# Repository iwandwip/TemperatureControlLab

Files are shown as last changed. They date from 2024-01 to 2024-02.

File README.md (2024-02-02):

# Temperature Control Lab - AP Monitor
The temperature control lab is an application of feedback control with an Arduino, an LED, two heaters, and two temperature sensors. The heater power output is adjusted to maintain a desired temperature setpoint. Thermal energy from the heater is transferred by conduction, convection, and radiation to the temperature sensor. Heat is also transferred away from the device to the surroundings.

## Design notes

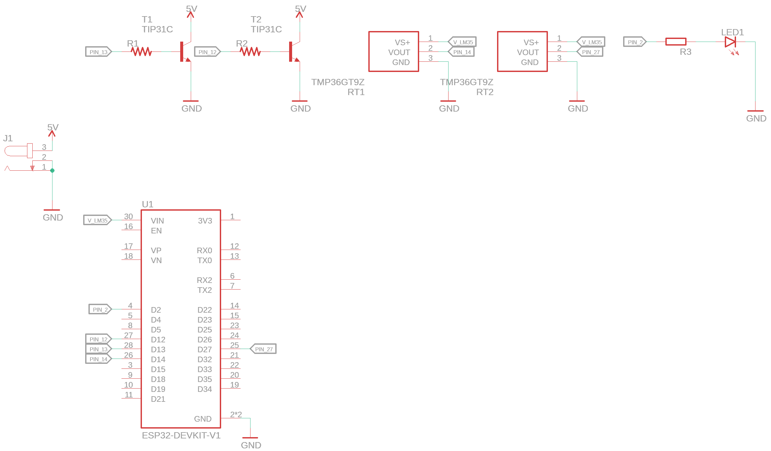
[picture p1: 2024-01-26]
pcb/esp32/sch.png

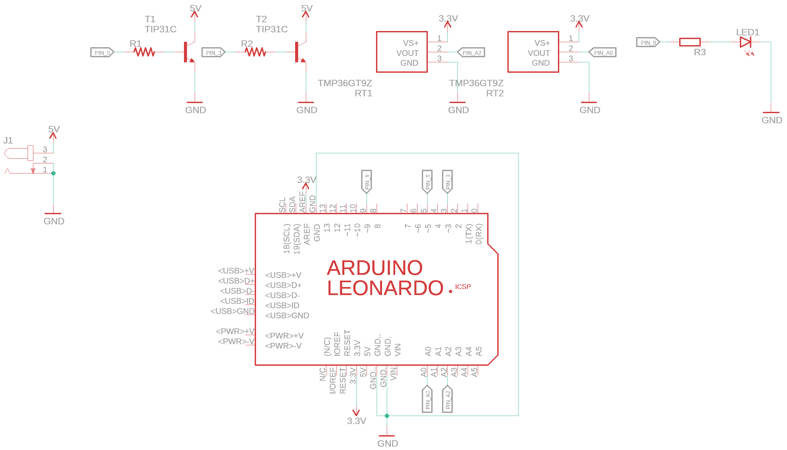
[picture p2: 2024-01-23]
pcb/leonardo/sch.png

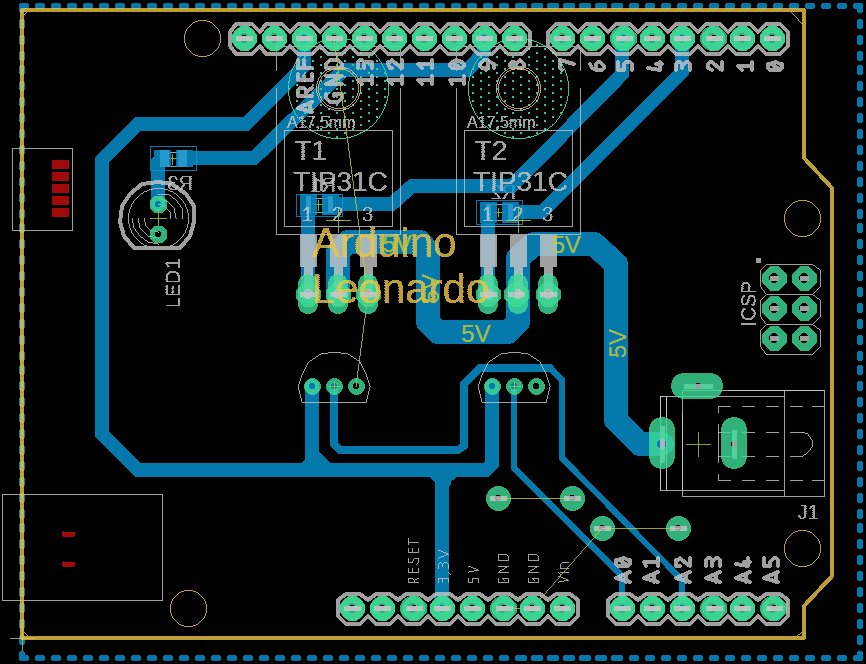
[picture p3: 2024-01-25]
pcb/leonardo/brd.png

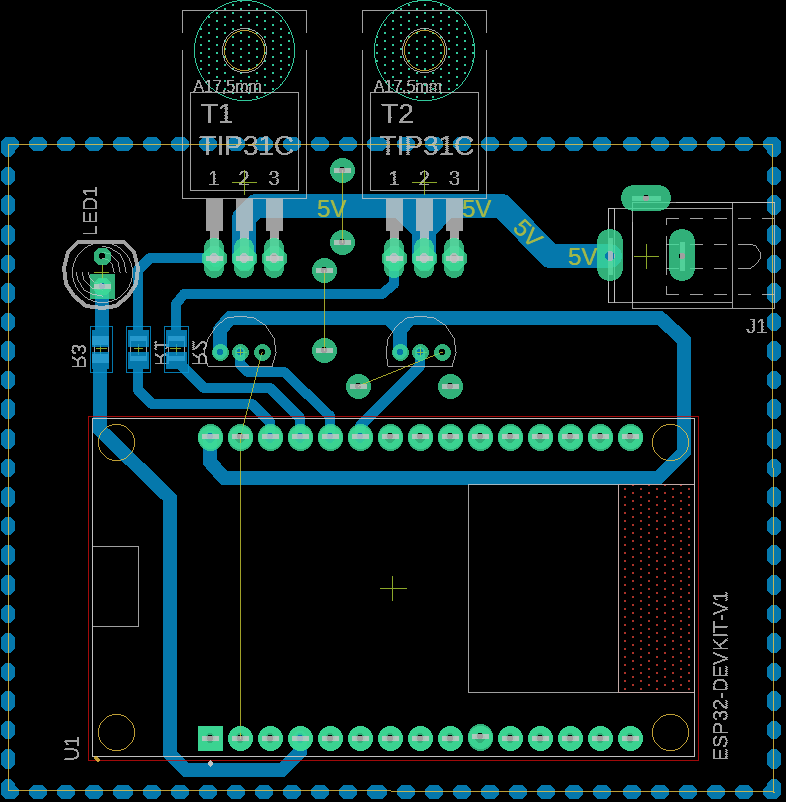
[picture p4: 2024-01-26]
pcb/esp32/brd.png

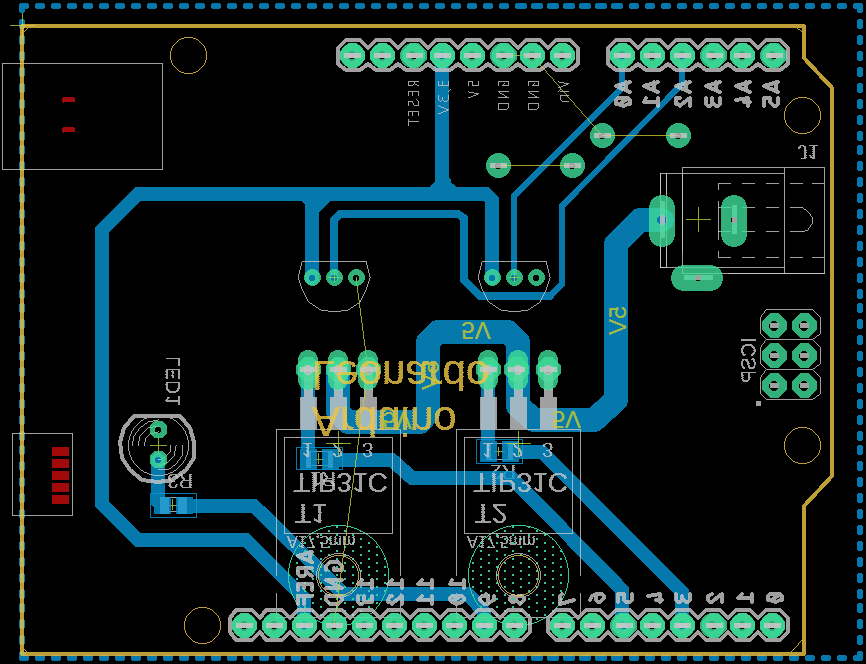
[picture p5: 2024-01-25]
pcb/leonardo/brd-mirror.png

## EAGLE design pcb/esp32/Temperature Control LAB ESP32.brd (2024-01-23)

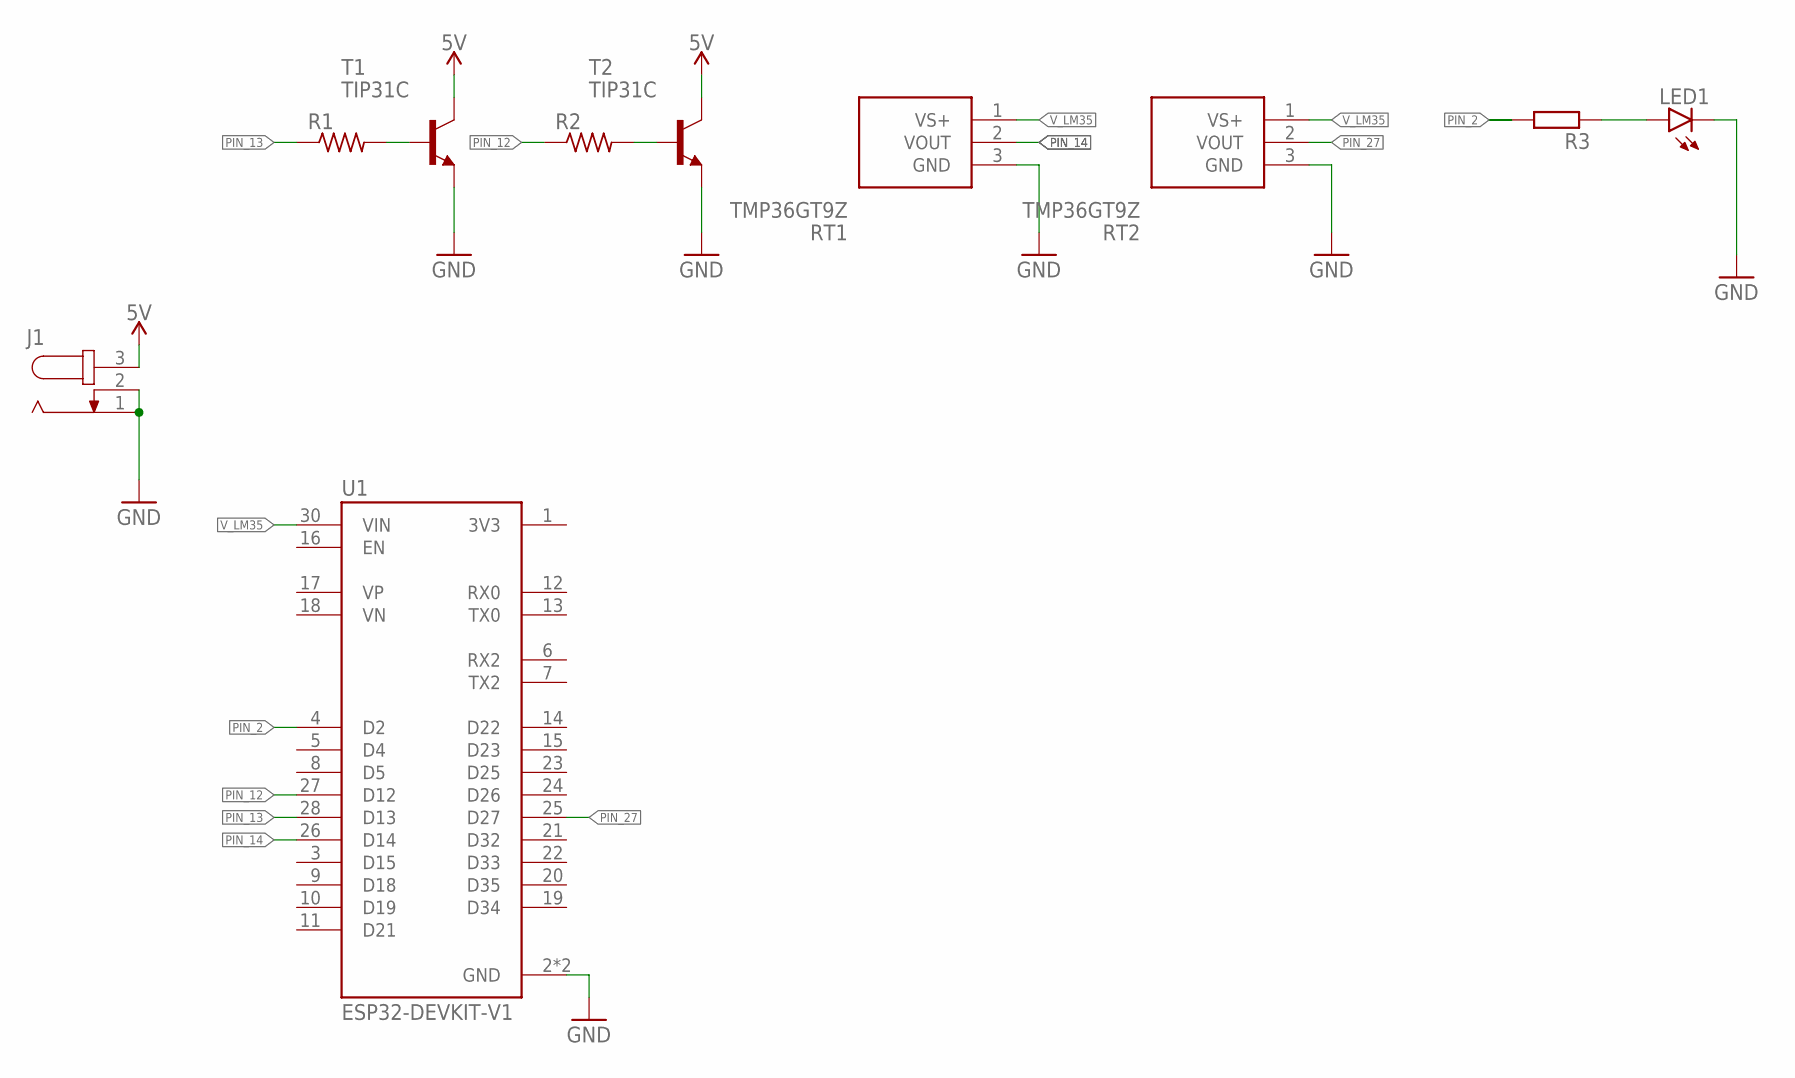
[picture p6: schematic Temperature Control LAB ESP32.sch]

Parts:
J1: JACK-PLUG0; SPC4077
LED1: LED5MM
R1, R2: R-US_M0805; M0805
R3: R-EU_R0805; R0805
RT1, RT2: TMP36GT9Z; TO-92
T1, T2: TIP31C; TO220
U1: ESP32-DEVKIT-V1; MODULE_ESP32_DEVKIT_V1

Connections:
5V: J1.3, T1.2 (C), T2.2 (C)
GND: J1.1, J1.2, LED1.K (C), RT1.3 (GND), RT2.3 (GND), T1.3 (E), T2.3 (E), U1.2 (GND), U1.29 (GND)
unnamed: R1.2, T1.1 (B)
unnamed: R2.2, T2.1 (B)
unnamed: LED1.A, R3.1
PIN_2: R3.2, U1.4 (D2)
PIN_12: R2.1, U1.27 (D12)
PIN_13: R1.1, U1.28 (D13)
PIN_14: RT1.2 (VOUT), U1.26 (D14)
PIN_27: RT2.2 (VOUT), U1.25 (D27)
V_LM35: RT1.1 (VS+), RT2.1 (VS+), U1.30 (VIN)

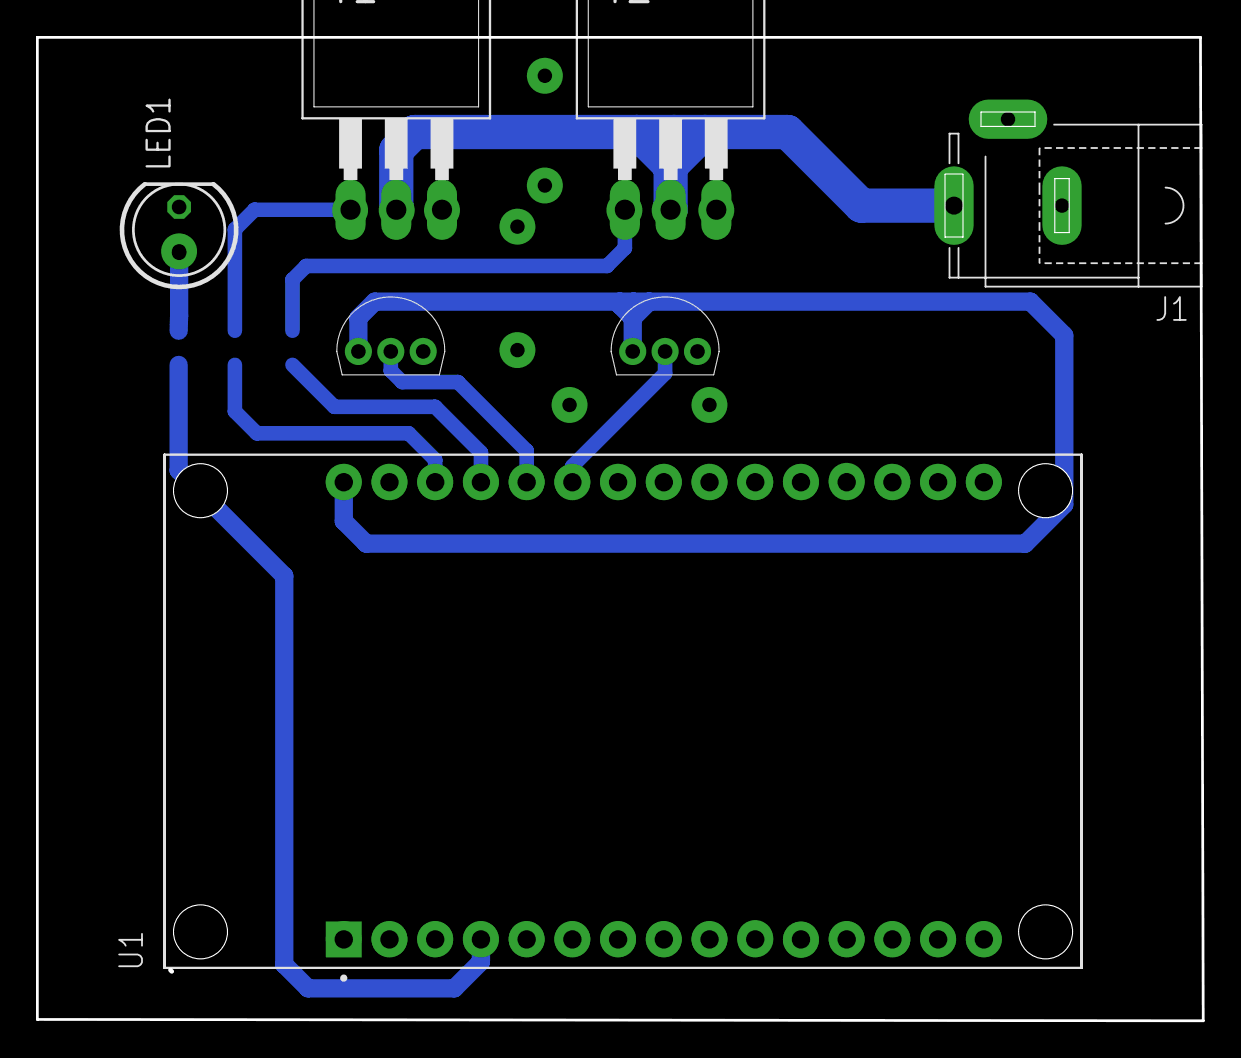
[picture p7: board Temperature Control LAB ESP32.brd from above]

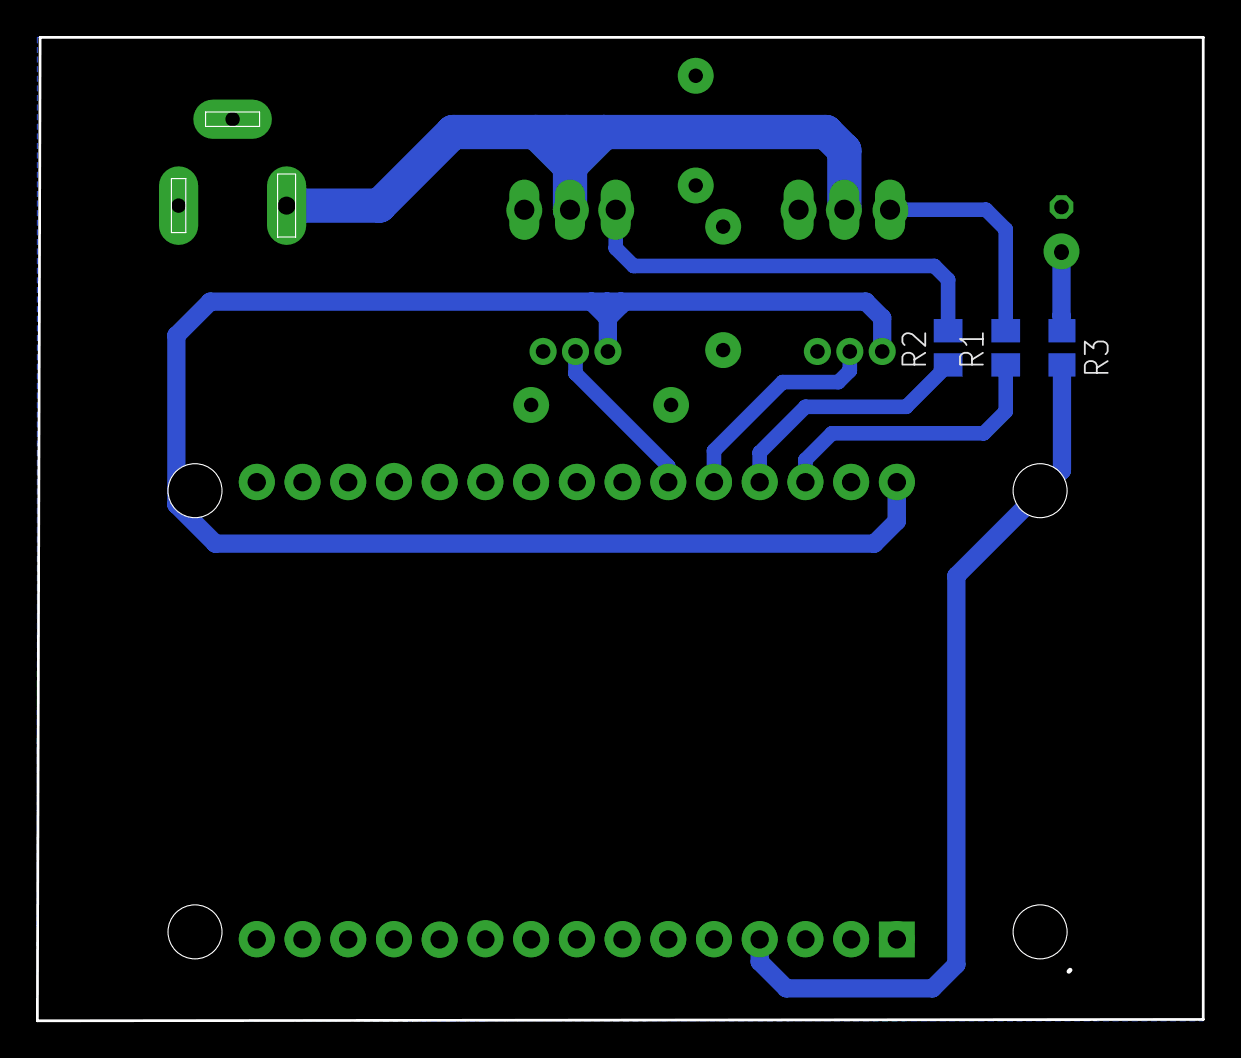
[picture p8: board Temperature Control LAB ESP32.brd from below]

Board: 2 copper layers, 64.8 x 54.6 mm, 10 parts (3 on the bottom side), 11 nets.

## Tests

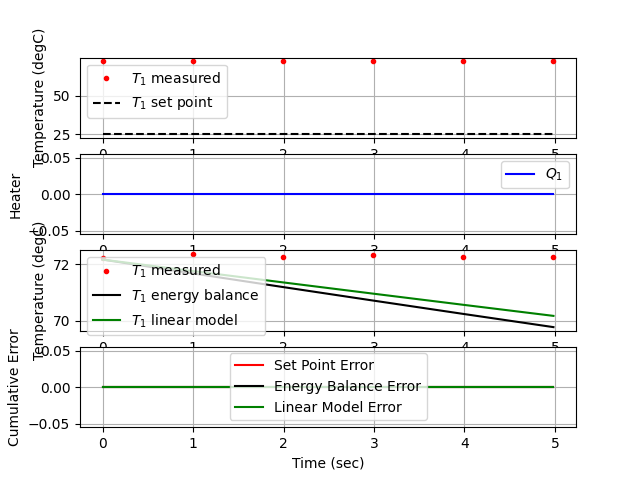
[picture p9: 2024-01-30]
sketch/py/test_PID.png

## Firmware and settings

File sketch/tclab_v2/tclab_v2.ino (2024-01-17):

/* https://apmonitor.com/pdc/index.php/Main/ArduinoTemperatureControl
  TCLab Temperature Control Lab Firmware
  Jeffrey Kantor, Bill Tubbs, John Hedengren, Shawn Summey
  February 2021

  This firmware provides a high level interface to the Temperature Control Lab. The
  firmware scans the serial port for commands. Commands are case-insensitive. Any
  unrecognized command results in sleep model. Each command returns a result string.

  A         software restart. Returns "Start".
  LED float set LED to float for 10 sec. range 0 to 100. Returns actual float
  P1 float  set pwm limit on heater 1, range 0 to 255. Default 200. Returns P1.
  P2 float  set pwm limit on heater 2, range 0 to 255. Default 100. Returns P2.
  Q1 float  set Heater 1, range 0 to 100. Returns value of Q1.
  Q2 float  set Heater 2, range 0 to 100. Returns value of Q2.
  Q1B float set Heater 1, range 0 to 100. Returns value of Q1 as a 32-bit float.
  Q2B float set Heater 2, range 0 to 100. Returns value of Q2 as a 32-bit float.
  R1        get value of Heater 1, range 0 to 100
  R2        get value of Heater 2, range 0 to 100
  SCAN      get values T1 T2 Q1 Q1 in line delimited values
  T1        get Temperature T1. Returns value of T1 in °C.
  T2        get Temperature T2. Returns value of T2 in °C.
  T1B       get Temperature T1. Returns value of T1 in °C as a 32-bit float.
  T2B       get Temperature T2. Returns value of T2 in °C as a 32-bit float.
  VER       get firmware version string
  X         stop, enter sleep mode. Returns "Stop"

  Limits on the heater power can be configured with the constants below.

  Status is indicated by LED1 on the Temperature Control Lab. Status conditions are:

      LED1        LED1
      Brightness  State
      ----------  -----
      dim         steady     Normal operation, heaters off
      bright      steady     Normal operation, heaters on
      dim         blinking   High temperature alarm on, heaters off
      bright      blinking   High temperature alarm on, heaters on

  The Temperature Control Lab shuts down the heaters if it receives no host commands
  during a timeout period (configure below), receives an "X" command, or receives
  an unrecognized command from the host.

  Constants are used to configure the firmware.

  Changelog ordered by Semantic Version
  
      1.0.1 first version included in the tclab package
      1.1.0 added R1 and R2 commands to read current heater values
            changed heater values to units of percent of full power
            added P1 and P2 commands to set heater power limits
            changed readCommand to avoid busy states
            changed simplified LED status model
      1.2.0 added LED command
      1.2.1 fixed reset heater values on close
            added version history
      1.2.2 changed version string for better display by TCLab
      1.2.3 changed baudrate to from 9600 to 115200
      1.3.0 added SCAN function 
            added board type in version string
      1.4.0 changed Q1 and Q2 to float from int
      1.4.1 fixed missing Serial.flush() at end of command loop
      1.4.2 fixed bug with X command
      1.4.3 deprecated use of Arduino IDE Version < 1.0.0
      1.5.0 removed webusb
      1.6.0 changed temperature to average 10 measurements to reduce noise
      2.0.0 added binary communications.
            added T1B and T2B commands return 32-bit float
            added Q1B and Q2B commands return 32-bit float confirmation of heater setting
            added calculation to use 1.75 AREF to match TMP36 voltage range 
      2.0.1 added updates to Notre Dame and BYU versions of this firmware
            changed version history to standard change log practices

*/

#include "Arduino.h"

// determine board type
#if defined(__AVR_ATmega328P__) || defined(__AVR_ATmega168__)
String boardType = "Arduino Uno";
#elif defined(__AVR_ATmega32U4__) || defined(__AVR_ATmega16U4__)
String boardType = "Arduino Leonardo/Micro";
#elif defined(__AVR_ATmega1280__) || defined(__AVR_ATmega2560__)
String boardType = "Arduino Mega";
#else
String boardType = "Unknown board";
#endif

// Enable debugging output
const bool DEBUG = false;

// constants
const String vers = "2.0.1";  // version of this firmware
const long baud = 115200;     // serial baud rate
const char sp = ' ';          // command separator
const char nl = '\n';         // command terminator

// pin numbers corresponding to signals on the TC Lab Shield
const int pinT1 = A0;   // T1
const int pinT2 = A2;   // T2
const int pinQ1 = 3;    // Q1
const int pinQ2 = 5;    // Q2
const int pinLED1 = 9;  // LED1

// temperature alarm limits
const int limT1 = 50;  // T1 high alarm (°C)
const int limT2 = 50;  // T2 high alarm (°C)

// LED1 levels
const int hiLED = 60;          // hi LED
const int loLED = hiLED / 16;  // lo LED

// global variables
char Buffer[64];          // buffer for parsing serial input
int buffer_index = 0;     // index for Buffer
String cmd;               // command
float val;                // command value
int ledStatus;            // 1: loLED
                          // 2: hiLED
                          // 3: loLED blink
                          // 4: hiLED blink
long ledTimeout = 0;      // when to return LED to normal operation
float LED = 100;          // LED override brightness
float P1 = 200;           // heater 1 power limit in units of pwm. Range 0 to 255
float P2 = 100;           // heater 2 power limit in units in pwm, range 0 to 255
float Q1 = 0;             // last value written to heater 1 in units of percent
float Q2 = 0;             // last value written to heater 2 in units of percent
int alarmStatus;          // hi temperature alarm status
boolean newData = false;  // boolean flag indicating new command
int n = 10;               // number of samples for each temperature measurement


void readCommand() {
  while (Serial && (Serial.available() > 0) && (newData == false)) {
    int byte = Serial.read();
    if ((byte != '\r') && (byte != nl) && (buffer_index < 64)) {
      Buffer[buffer_index] = byte;
      buffer_index++;
    } else {
      newData = true;
    }
  }
}

// for debugging with the serial monitor in Arduino IDE
void echoCommand() {
  if (newData) {
    Serial.write("Received Command: ");
    Serial.write(Buffer, buffer_index);
    Serial.write(nl);
    Serial.flush();
  }
}

// return average  of n reads of thermister temperature in °C
inline float readTemperature(int pin) {
  float degC = 0.0;
  for (int i = 0; i < n; i++) {
    degC += analogRead(pin) * 0.322265625 - 50.0;  // use for 3.3v AREF
    //degC += analogRead(pin) * 0.170898438 - 50.0;  // use for 1.75v AREF
  }
  return degC / float(n);
}

void parseCommand(void) {
  if (newData) {
    String read_ = String(Buffer);

    // separate command from associated data
    int idx = read_.indexOf(sp);
    cmd = read_.substring(0, idx);
    cmd.trim();
    cmd.toUpperCase();

    // extract data. toFloat() returns 0 on error
    String data = read_.substring(idx + 1);
    data.trim();
    val = data.toFloat();

    // reset parameter for next command
    memset(Buffer, 0, sizeof(Buffer));
    buffer_index = 0;
    newData = false;
  }
}

void sendResponse(String msg) {
  Serial.println(msg);
}

void sendFloatResponse(float val) {
  Serial.println(String(val, 3));
}

void sendBinaryResponse(float val) {
  byte *b = (byte *)&val;
  Serial.write(b, 4);
}

void dispatchCommand(void) {
  if (cmd == "A") {
    setHeater1(0);
    setHeater2(0);
    sendResponse("Start");
  } else if (cmd == "LED") {
    ledTimeout = millis() + 10000;
    LED = max(0, min(100, val));
    sendResponse(String(LED));
  } else if (cmd == "P1") {
    P1 = max(0, min(255, val));
    sendResponse(String(P1));
  } else if (cmd == "P2") {
    P2 = max(0, min(255, val));
    sendResponse(String(P2));
  } else if (cmd == "Q1") {
    setHeater1(val);
    sendFloatResponse(Q1);
  } else if (cmd == "Q1B") {
    setHeater1(val);
    sendBinaryResponse(Q1);
  } else if (cmd == "Q2") {
    setHeater2(val);
    sendFloatResponse(Q2);
  } else if (cmd == "Q2B") {
    setHeater1(val);
    sendBinaryResponse(Q2);
  } else if (cmd == "R1") {
    sendFloatResponse(Q1);
  } else if (cmd == "R2") {
    sendFloatResponse(Q2);
  } else if (cmd == "SCAN") {
    sendFloatResponse(readTemperature(pinT1));
    sendFloatResponse(readTemperature(pinT2));
    sendFloatResponse(Q1);
    sendFloatResponse(Q2);
  } else if (cmd == "T1") {
    sendFloatResponse(readTemperature(pinT1));
  } else if (cmd == "T1B") {
    sendBinaryResponse(readTemperature(pinT1));
  } else if (cmd == "T2") {
    sendFloatResponse(readTemperature(pinT2));
  } else if (cmd == "T2B") {
    sendBinaryResponse(readTemperature(pinT2));
  } else if (cmd == "VER") {
    sendResponse("TCLab Firmware " + vers + " " + boardType);
  } else if (cmd == "X") {
    setHeater1(0);
    setHeater2(0);
    sendResponse("Stop");
  } else if (cmd.length() > 0) {
    setHeater1(0);
    setHeater2(0);
    sendResponse(cmd);
  }
  Serial.flush();
  cmd = "";
}

void checkAlarm(void) {
  if ((readTemperature(pinT1) > limT1) or (readTemperature(pinT2) > limT2)) {
    alarmStatus = 1;
  } else {
    alarmStatus = 0;
  }
}

void updateStatus(void) {
  // determine led status
  ledStatus = 1;
  if ((Q1 > 0) or (Q2 > 0)) {
    ledStatus = 2;
  }
  if (alarmStatus > 0) {
    ledStatus += 2;
  }
  // update led depending on ledStatus
  if (millis() < ledTimeout) {  // override led operation
    analogWrite(pinLED1, LED);
  } else {
    switch (ledStatus) {
      case 1:  // normal operation, heaters off
        analogWrite(pinLED1, loLED);
        break;
      case 2:  // normal operation, heater on
        analogWrite(pinLED1, hiLED);
        break;
      case 3:  // high temperature alarm, heater off
        if ((millis() % 2000) > 1000) {
          analogWrite(pinLED1, loLED);
        } else {
          analogWrite(pinLED1, loLED / 4);
        }
        break;
      case 4:  // high temperature alarm, heater on
        if ((millis() % 2000) > 1000) {
          analogWrite(pinLED1, hiLED);
        } else {
          analogWrite(pinLED1, loLED);
        }
        break;
    }
  }
}

// set Heater 1
void setHeater1(float qval) {
  Q1 = max(0., min(qval, 100.));
  analogWrite(pinQ1, (Q1 * P1) / 100);
}

// set Heater 2
void setHeater2(float qval) {
  Q2 = max(0., min(qval, 100.));
  analogWrite(pinQ2, (Q2 * P2) / 100);
}

// arduino startup
void setup() {
  analogReference(EXTERNAL);
  while (!Serial) {
    ;  // wait for serial port to connect.
  }
  Serial.begin(baud);
  Serial.flush();
  setHeater1(0);
  setHeater2(0);
  ledTimeout = millis() + 1000;
}

// arduino main event loop
void loop() {
  readCommand();
  if (DEBUG) echoCommand();
  parseCommand();
  dispatchCommand();
  checkAlarm();
  updateStatus();
}

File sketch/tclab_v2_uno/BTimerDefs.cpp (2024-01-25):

/*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
THE SOFTWARE IS PROVIDED "AS IS", WITHOUT WARRANTY OF ANY KIND, EXPRESS OR
IMPLIED, INCLUDING BUT NOT LIMITED TO THE WARRANTIES OF MERCHANTABILITY,
FITNESS FOR A PARTICULAR PURPOSE AND NONINFRINGEMENT. IN NO EVENT SHALL THE
AUTHORS OR COPYRIGHT HOLDERS BE LIABLE FOR ANY CLAIM, DAMAGES OR OTHER LIABILITY,
WHETHER IN AN ACTION OF CONTRACT, TORT OR OTHERWISE, ARISING FROM, OUT OF OR IN
CONNECTION WITH THE SOFTWARE OR THE USE OR OTHER DEALINGS IN THE SOFTWARE.
*/

#if defined(__AVR_ATmega48__) || defined(__AVR_ATmega88__) || defined(__AVR_ATmega88P__) || defined(__AVR_ATmega168__) || defined(__AVR_ATmega168P__) || defined(__AVR_ATmega328__) || defined(__AVR_ATmega328P__)

#include "wiring_private.h"
#include "PWM.h"

#define UINT16_MAX 65535
#define UINT8_MAX 255

//--------------------------------------------------------------------------------
//							Helper Functions
//--------------------------------------------------------------------------------

static float toBaseTwo(double baseTenNum) {
  return log(baseTenNum + 1) / log(2);
}

//--------------------------------------------------------------------------------
//							16 Bit Timer Functions
//--------------------------------------------------------------------------------

uint32_t GetFrequency_16() {
  return (int32_t)(F_CPU / (2 * (int32_t)GetTop_16() * GetPrescaler_16()));
}

bool SetFrequency_16(uint32_t f) {
  if (f > 2000000 || f < 1)
    return false;

  //find the smallest usable multiplier
  uint16_t multiplier = (int16_t)(F_CPU / (2 * f * UINT16_MAX));

  uint8_t iterate = 0;
  while (multiplier > pscLst[iterate++])
    ;

  multiplier = pscLst[iterate];  //multiplier holds the clock select value, and iterate holds the corresponding CS flag

  //getting the timer top using the new multiplier
  uint16_t timerTop = (uint16_t)(F_CPU / (2 * f * multiplier));

  SetTop_16(timerTop);
  SetPrescaler_16((prescaler)iterate);

  return true;
}

uint16_t GetPrescaler_16() {
  return pscLst[(TCCR1B & 7)];
}

void SetPrescaler_16(prescaler psc) {
  TCCR1B = (TCCR1B & ~7) | (psc & 7);
}

void SetTop_16(uint16_t top) {
  ICR1 = top;
}

uint16_t GetTop_16() {
  return ICR1;
}

void Initialize_16() {
  //setting the waveform generation mode
  uint8_t wgm = 8;

  TCCR1A = (TCCR1A & B11111100) | (wgm & 3);
  TCCR1B = (TCCR1B & B11100111) | ((wgm & 12) << 1);

  SetFrequency_16(500);
}

float GetResolution_16() {
  return toBaseTwo(ICR1);
}

//--------------------------------------------------------------------------------
//							8 Bit Timer Functions
//--------------------------------------------------------------------------------

uint32_t GetFrequency_8(const int16_t timerOffset) {
  return (uint32_t)(F_CPU / ((uint32_t)2 * GetTop_8(timerOffset) * GetPrescaler_8(timerOffset)));
}

bool SetFrequency_8(const int16_t timerOffset, uint32_t f) {
  if (f > 2000000 || f < 31)
    return false;

  //find the smallest usable multiplier
  uint16_t multiplier = (F_CPU / (2 * (uint32_t)f * UINT8_MAX));

  uint8_t iterate = 0;
  uint16_t timerTop;

  do {
    if (TIMER2_OFFSET != timerOffset) {
      while (multiplier > pscLst[++iterate])
        ;
      multiplier = pscLst[iterate];
    } else {
      while (multiplier > pscLst_alt[++iterate])
        ;
      multiplier = pscLst_alt[iterate];
    }

    //getting the timer top using the new multiplier
    timerTop = (F_CPU / (2 * f * (uint32_t)multiplier));

  } while (timerTop > UINT8_MAX);

  SetTop_8(timerOffset, timerTop);

  if (timerOffset != TIMER2_OFFSET)
    SetPrescaler_8(timerOffset, (prescaler)iterate);
  else
    SetPrescalerAlt_8(timerOffset, (prescaler_alt)iterate);

  return true;
}

uint16_t GetPrescaler_8(const int16_t timerOffset) {
  if (timerOffset != TIMER2_OFFSET)
    return pscLst[(TCCRB_8(timerOffset) & 7)];
  else
    return pscLst_alt[(TCCRB_8(timerOffset) & 7)];
}

void SetPrescaler_8(const int16_t timerOffset, prescaler psc) {
  TCCRB_8(timerOffset) = (TCCRB_8(timerOffset) & ~7) | (psc & 7);
}

void SetPrescalerAlt_8(const int16_t timerOffset, prescaler_alt psc) {
  TCCRB_8(timerOffset) = (TCCRB_8(timerOffset) & ~7) | (psc & 7);
}

void SetTop_8(const int16_t timerOffset, uint8_t top) {
  OCRA_8(timerOffset) = top;
}

uint8_t GetTop_8(const int16_t timerOffset) {
  return OCRA_8(timerOffset);
}

void Initialize_8(const int16_t timerOffset) {
  //setting the waveform generation mode
  uint8_t wgm = 5;

  TCCRA_8(timerOffset) = (TCCRA_8(timerOffset) & B11111100) | (wgm & 3);
  TCCRB_8(timerOffset) = (TCCRB_8(timerOffset) & B11110111) | ((wgm & 12) << 1);

  //disable timer0's interrupt when initialization is called, otherwise handler will eat
  //up processor cycles when PWM on timer0 is set to high frequencies. This will effectively disable
  //Arduino's time keeping functions, which the user should be aware of before initializing timer0
  if (timerOffset == 0) {
    TIMSK0 &= B11111110;
  }

  SetFrequency_8(timerOffset, 500);
}
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

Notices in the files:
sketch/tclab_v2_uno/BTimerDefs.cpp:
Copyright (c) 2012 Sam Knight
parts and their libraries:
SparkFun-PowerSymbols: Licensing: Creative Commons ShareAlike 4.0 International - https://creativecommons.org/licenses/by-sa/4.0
